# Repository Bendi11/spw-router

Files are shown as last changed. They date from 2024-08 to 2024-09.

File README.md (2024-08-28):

# 8 Port SpaceWire Router
A hobby-grade [SpaceWire](https://www.esa.int/Enabling_Support/Space_Engineering_Technology/Onboard_Computers_and_Data_Handling/SpaceWire) router
aiming for full **ECSS-E-ST-50-12C** compliance utilizing a Xilinx Artix 7 FPGA.

## Hardware Development
KiCad schematics and board design files for the board are stored in the `hw/board` directory.
Custom footprints and 3D models are placed into the `hw/models` directory.

## FPGA
Verilog sources are located in the `rtl/src` directory, and both the synthesis and simulation
processes are managed by CMake.

Currently, the FPGA bitstream is generated with a fully open-source
[yosys](https://github.com/YosysHQ/yosys) + [nextpnr-xilinx](https://github.com/gatecat/nextpnr-xilinx) flow,
and does not require the Xilinx Vivado software.
Paths to the required tools must currently be provided in an `env.cmake` file located in the
`rtl/cmake` directory, which must set the following:

| Variable Name | Description |
| :---: | --- |
| **YOSYS** | Path to the `yosys` binary |
| **NEXTPNR_XILINX** | Path to the `nextpnr-xilinx` binary, usually found at the root of the `nextpnr-xilinx` repository after building |
| **XRAY_DB_DIR** | Path to the Project X-Ray database |
| **XRAY_FASM2FRAMES** | Command to use the `fasm2frames` tool provided in Project X-Ray. This python script may have to run in Project X-Ray's virtual environment, so this variable is typically `"${PRJXRAY_DIR}/env/bin/python3" "${XRAY_DIR}/utils/fasm2frames.py"` |
| **XRAY_XC7FRAMES2BIT** | Path to the Project X-Ray's `xc7frames2bit` binary, usually in `${PRJXRAY_DIR}/build/tools/` |

### Example env.cmake
```cmake
set(NEXTPNR_XILINX_DIR "$ENV{HOME}/nextpnr-xilinx")
set(XRAY_DIR "$ENV{HOME}/prjxray")
set(XRAY_DB_DIR "${NEXTPNR_XILINX_DIR}/xilinx/external/prjxray-db")

set(YOSYS "yosys")
set(NEXTPNR_XILINX "${NEXTPNR_XILINX_DIR}/nextpnr-xilinx")
set(XRAY_FASM2FRAMES "${XRAY_DIR}/env/bin/python3" "${XRAY_DIR}/utils/fasm2frames.py")
set(XC7FRAMES2BIT "${XRAY_DIR}/build/tools/xc7frames2bit")
```

Design verification is performed with [Verilator](https://www.veripool.org/verilator/), with simulation
shims for Xilinx hard IP located in the `rtl/sim/verilog` directory.

## STM32 Software
`TODO`

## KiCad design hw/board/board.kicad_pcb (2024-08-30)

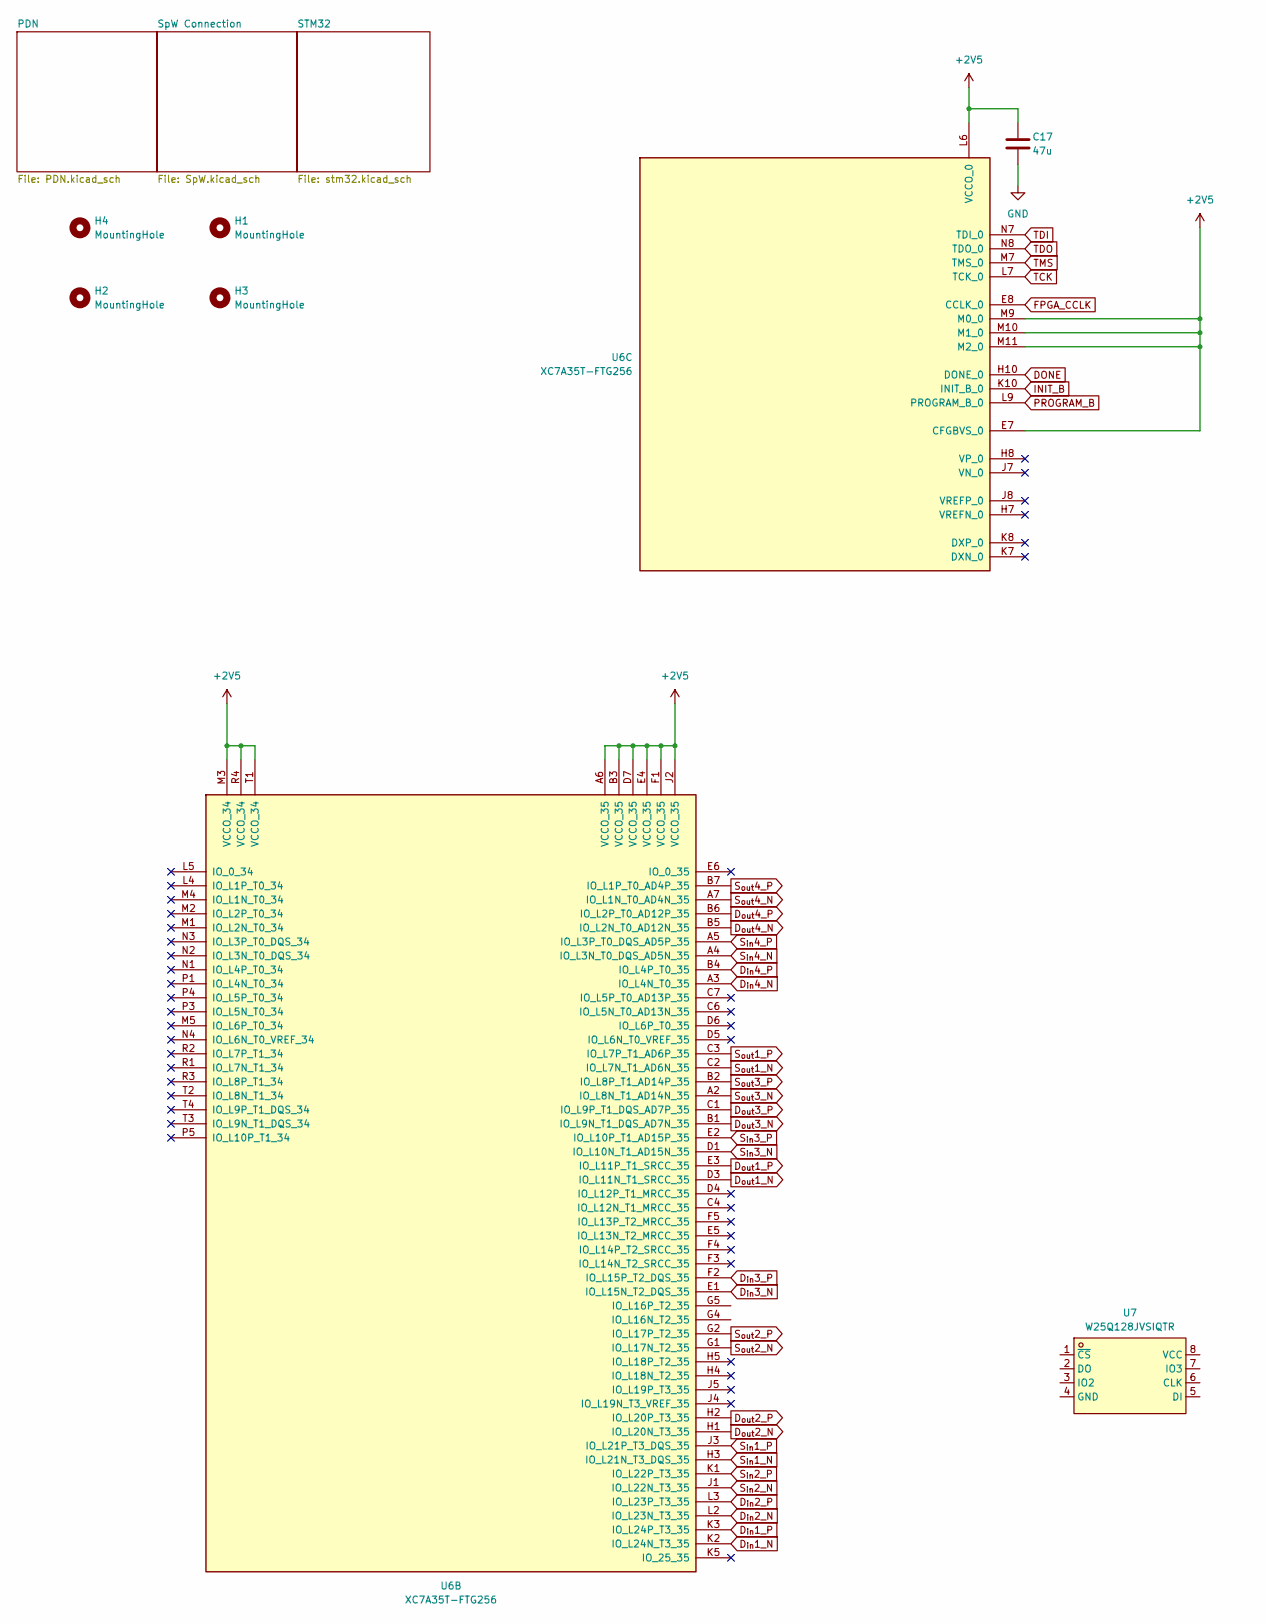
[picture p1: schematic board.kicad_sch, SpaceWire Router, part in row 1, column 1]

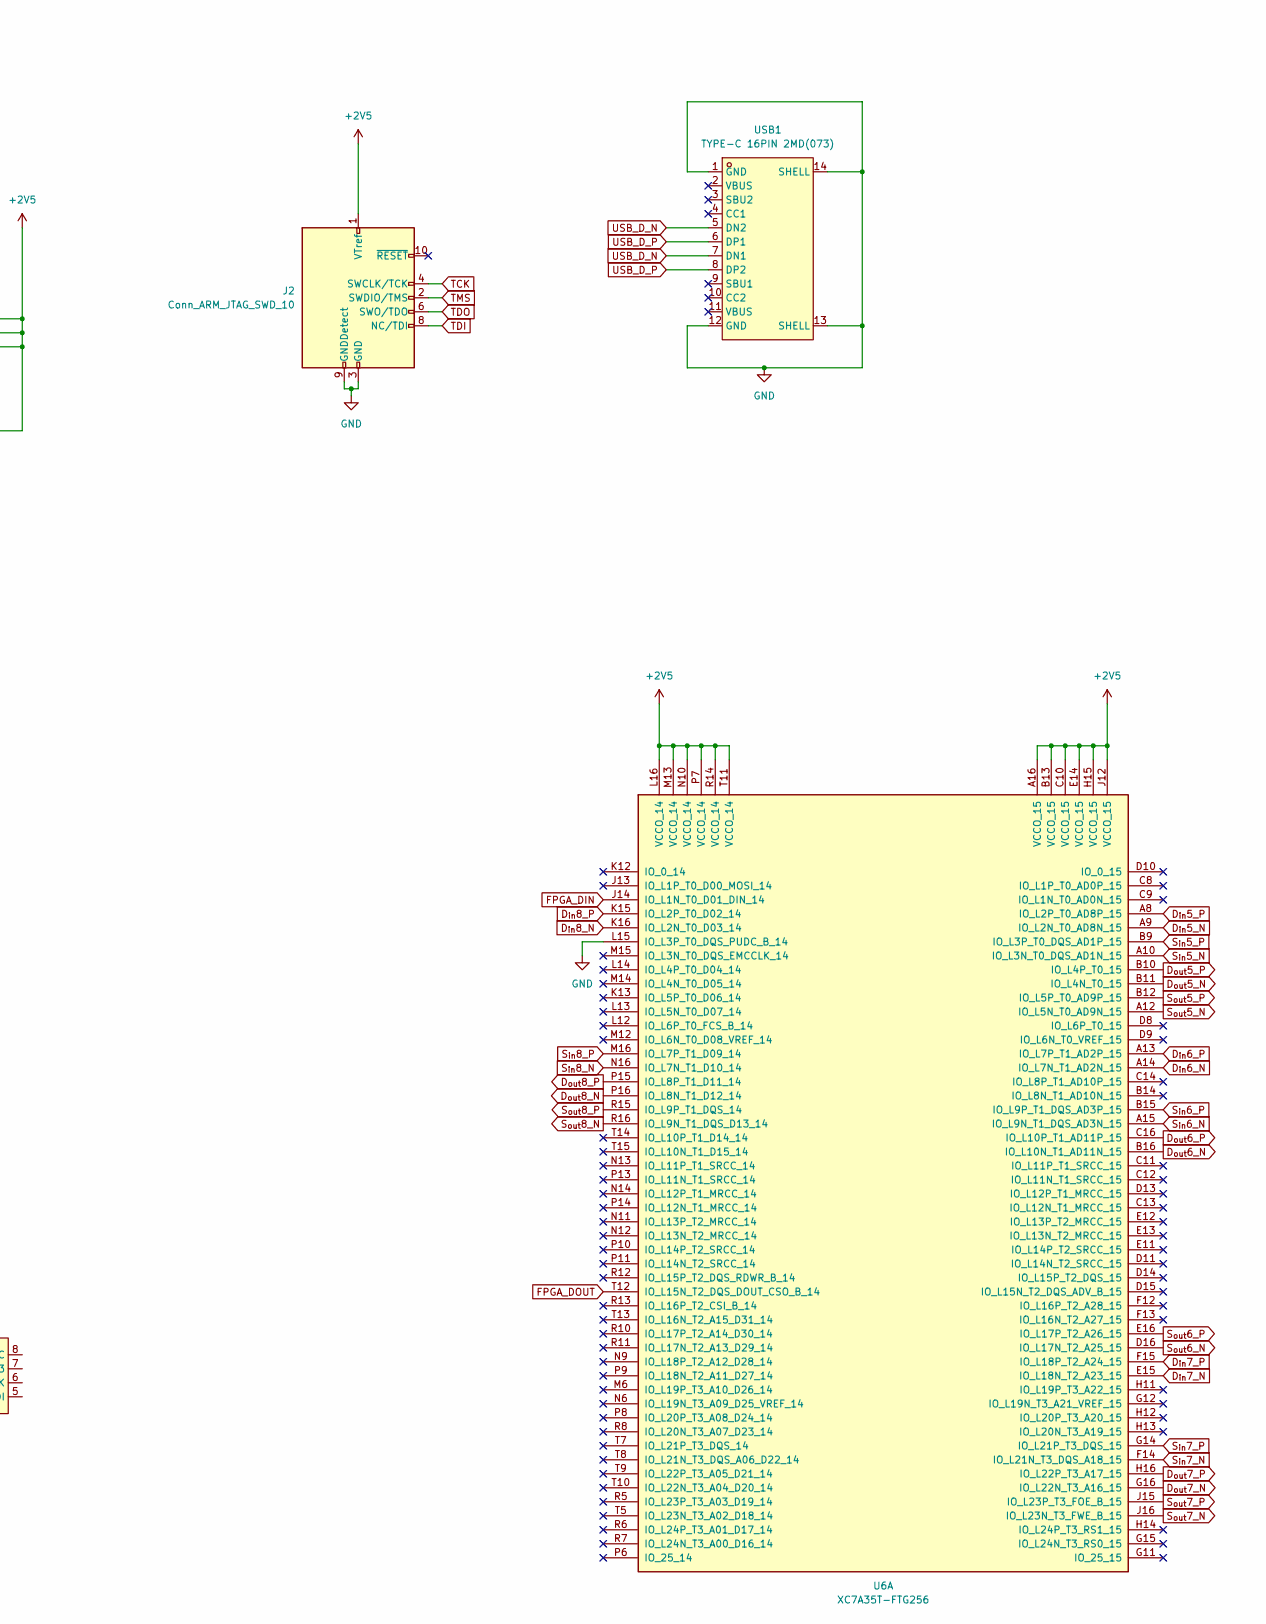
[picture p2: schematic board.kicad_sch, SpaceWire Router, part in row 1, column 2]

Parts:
C17: 47u; C_0805_2012Metric
H1, H2, H3, H4: MountingHole; MountingHole_2.2mm_M2
J2: Conn_ARM_JTAG_SWD_10; PinHeader_2x05_P1.27mm_Vertical
U6: XC7A35T-FTG256; Xilinx_FTG256
U7: W25Q128JVSIQTR; SOIC-8_L5.3-W5.3-P1.27-LS8.0-BL; LCSC Part C97521
USB1: TYPE-C 16PIN 2MD(073); USB-C-SMD_TYPE-C-6PIN-2MD-073; LCSC Part C2765186

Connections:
+2V5: C17.1, J2.1 (VTref), U6.A6 (VCCO_35), U6.A16 (VCCO_15), U6.B3 (VCCO_35), U6.B13 (VCCO_15), U6.C10 (VCCO_15), U6.D7 (VCCO_35), U6.E4 (VCCO_35), U6.E7 (CFGBVS_0), U6.E14 (VCCO_15), U6.F1 (VCCO_35), U6.H15 (VCCO_15), U6.J2 (VCCO_35), U6.J12 (VCCO_15), U6.L6 (VCCO_0), U6.L16 (VCCO_14), U6.M3 (VCCO_34), U6.M9 (M0_0), U6.M10 (M1_0), U6.M11 (M2_0), U6.M13 (VCCO_14), U6.N10 (VCCO_14), U6.P7 (VCCO_14), U6.R4 (VCCO_34), U6.R14 (VCCO_14), U6.T1 (VCCO_34), U6.T11 (VCCO_14); also elsewhere on the board
DONE: U6.H10 (DONE_0); also elsewhere on the board
D_{in}1_N: U6.K2 (IO_L24N_T3_35); also elsewhere on the board
D_{in}1_P: U6.K3 (IO_L24P_T3_35); also elsewhere on the board
D_{in}2_N: U6.L2 (IO_L23N_T3_35); also elsewhere on the board
D_{in}2_P: U6.L3 (IO_L23P_T3_35); also elsewhere on the board
D_{in}3_N: U6.E1 (IO_L15N_T2_DQS_35); also elsewhere on the board
D_{in}3_P: U6.F2 (IO_L15P_T2_DQS_35); also elsewhere on the board
D_{in}4_N: U6.A3 (IO_L4N_T0_35); also elsewhere on the board
D_{in}4_P: U6.B4 (IO_L4P_T0_35); also elsewhere on the board
D_{in}5_N: U6.A9 (IO_L2N_T0_AD8N_15); also elsewhere on the board
D_{in}5_P: U6.A8 (IO_L2P_T0_AD8P_15); also elsewhere on the board
D_{in}6_N: U6.A14 (IO_L7N_T1_AD2N_15); also elsewhere on the board
D_{in}6_P: U6.A13 (IO_L7P_T1_AD2P_15); also elsewhere on the board
D_{in}7_N: U6.E15 (IO_L18N_T2_A23_15); also elsewhere on the board
D_{in}7_P: U6.F15 (IO_L18P_T2_A24_15); also elsewhere on the board
D_{in}8_N: U6.K16 (IO_L2N_T0_D03_14); also elsewhere on the board
D_{in}8_P: U6.K15 (IO_L2P_T0_D02_14); also elsewhere on the board
D_{out}1_N: U6.D3 (IO_L11N_T1_SRCC_35); also elsewhere on the board
D_{out}1_P: U6.E3 (IO_L11P_T1_SRCC_35); also elsewhere on the board
D_{out}2_N: U6.H1 (IO_L20N_T3_35); also elsewhere on the board
D_{out}2_P: U6.H2 (IO_L20P_T3_35); also elsewhere on the board
D_{out}3_N: U6.B1 (IO_L9N_T1_DQS_AD7N_35); also elsewhere on the board
D_{out}3_P: U6.C1 (IO_L9P_T1_DQS_AD7P_35); also elsewhere on the board
D_{out}4_N: U6.B5 (IO_L2N_T0_AD12N_35); also elsewhere on the board
D_{out}4_P: U6.B6 (IO_L2P_T0_AD12P_35); also elsewhere on the board
D_{out}5_N: U6.B11 (IO_L4N_T0_15); also elsewhere on the board
D_{out}5_P: U6.B10 (IO_L4P_T0_15); also elsewhere on the board
D_{out}6_N: U6.B16 (IO_L10N_T1_AD11N_15); also elsewhere on the board
D_{out}6_P: U6.C16 (IO_L10P_T1_AD11P_15); also elsewhere on the board
D_{out}7_N: U6.G16 (IO_L22N_T3_A16_15); also elsewhere on the board
D_{out}7_P: U6.H16 (IO_L22P_T3_A17_15); also elsewhere on the board
D_{out}8_N: U6.P16 (IO_L8N_T1_D12_14); also elsewhere on the board
D_{out}8_P: U6.P15 (IO_L8P_T1_D11_14); also elsewhere on the board
FPGA_CCLK: U6.E8 (CCLK_0); also elsewhere on the board
FPGA_DIN: U6.J14 (IO_L1N_T0_D01_DIN_14); also elsewhere on the board
FPGA_DOUT: U6.T12 (IO_L15N_T2_DQS_DOUT_CSO_B_14); also elsewhere on the board
GND: C17.2, J2.3 (GND), J2.5 (GND), J2.9 (GNDDetect), U6.L15 (IO_L3P_T0_DQS_PUDC_B_14), USB1.1 (GND), USB1.12 (GND), USB1.13 (SHELL), USB1.14 (SHELL); also elsewhere on the board
INIT_B: U6.K10 (INIT_B_0); also elsewhere on the board
PROGRAM_B: U6.L9 (PROGRAM_B_0); also elsewhere on the board
S_{in}1_N: U6.H3 (IO_L21N_T3_DQS_35); also elsewhere on the board
S_{in}1_P: U6.J3 (IO_L21P_T3_DQS_35); also elsewhere on the board
S_{in}2_N: U6.J1 (IO_L22N_T3_35); also elsewhere on the board
S_{in}2_P: U6.K1 (IO_L22P_T3_35); also elsewhere on the board
S_{in}3_N: U6.D1 (IO_L10N_T1_AD15N_35); also elsewhere on the board
S_{in}3_P: U6.E2 (IO_L10P_T1_AD15P_35); also elsewhere on the board
S_{in}4_N: U6.A4 (IO_L3N_T0_DQS_AD5N_35); also elsewhere on the board
S_{in}4_P: U6.A5 (IO_L3P_T0_DQS_AD5P_35); also elsewhere on the board
S_{in}5_N: U6.A10 (IO_L3N_T0_DQS_AD1N_15); also elsewhere on the board
S_{in}5_P: U6.B9 (IO_L3P_T0_DQS_AD1P_15); also elsewhere on the board
S_{in}6_N: U6.A15 (IO_L9N_T1_DQS_AD3N_15); also elsewhere on the board
S_{in}6_P: U6.B15 (IO_L9P_T1_DQS_AD3P_15); also elsewhere on the board
S_{in}7_N: U6.F14 (IO_L21N_T3_DQS_A18_15); also elsewhere on the board
S_{in}7_P: U6.G14 (IO_L21P_T3_DQS_15); also elsewhere on the board
S_{in}8_N: U6.N16 (IO_L7N_T1_D10_14); also elsewhere on the board
S_{in}8_P: U6.M16 (IO_L7P_T1_D09_14); also elsewhere on the board
S_{out}1_N: U6.C2 (IO_L7N_T1_AD6N_35); also elsewhere on the board
S_{out}1_P: U6.C3 (IO_L7P_T1_AD6P_35); also elsewhere on the board
S_{out}2_N: U6.G1 (IO_L17N_T2_35); also elsewhere on the board
S_{out}2_P: U6.G2 (IO_L17P_T2_35); also elsewhere on the board
S_{out}3_N: U6.A2 (IO_L8N_T1_AD14N_35); also elsewhere on the board
S_{out}3_P: U6.B2 (IO_L8P_T1_AD14P_35); also elsewhere on the board
S_{out}4_N: U6.A7 (IO_L1N_T0_AD4N_35); also elsewhere on the board
S_{out}4_P: U6.B7 (IO_L1P_T0_AD4P_35); also elsewhere on the board
S_{out}5_N: U6.A12 (IO_L5N_T0_AD9N_15); also elsewhere on the board
S_{out}5_P: U6.B12 (IO_L5P_T0_AD9P_15); also elsewhere on the board
S_{out}6_N: U6.D16 (IO_L17N_T2_A25_15); also elsewhere on the board
S_{out}6_P: U6.E16 (IO_L17P_T2_A26_15); also elsewhere on the board
S_{out}7_N: U6.J16 (IO_L23N_T3_FWE_B_15); also elsewhere on the board
S_{out}7_P: U6.J15 (IO_L23P_T3_FOE_B_15); also elsewhere on the board
S_{out}8_N: U6.R16 (IO_L9N_T1_DQS_D13_14); also elsewhere on the board
S_{out}8_P: U6.R15 (IO_L9P_T1_DQS_14); also elsewhere on the board
TCK: J2.4 (SWCLK/TCK), U6.L7 (TCK_0)
TDI: J2.8 (NC/TDI), U6.N7 (TDI_0)
TDO: J2.6 (SWO/TDO), U6.N8 (TDO_0)
TMS: J2.2 (SWDIO/TMS), U6.M7 (TMS_0)
USB_D_N: USB1.5 (DN2), USB1.7 (DN1); also elsewhere on the board
USB_D_P: USB1.6 (DP1), USB1.8 (DP2); also elsewhere on the board

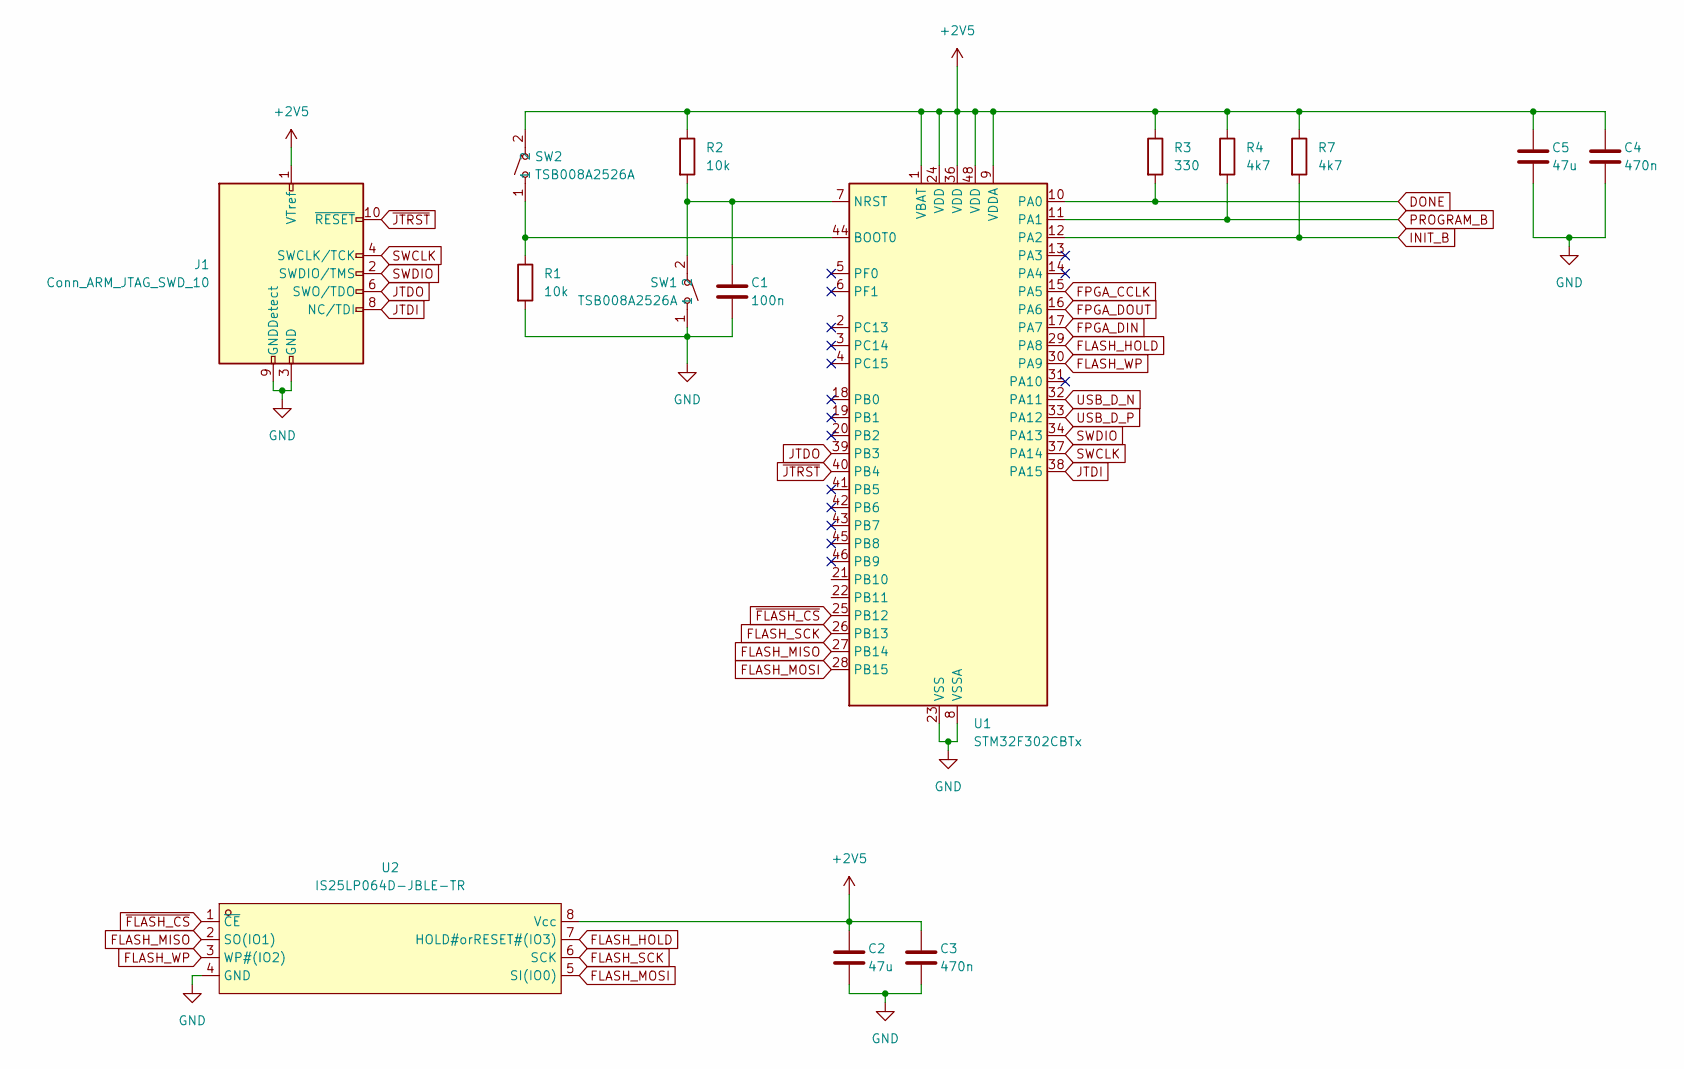
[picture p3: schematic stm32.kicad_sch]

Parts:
C1: 100n; C_0805_2012Metric
C2, C5: 47u; C_0805_2012Metric
C3, C4: 470n; C_0805_2012Metric
J1: Conn_ARM_JTAG_SWD_10; PinHeader_2x05_P1.27mm_Vertical
R1, R2: 10k; R_0805_2012Metric
R3: 330; R_0805_2012Metric
R4, R7: 4k7; R_0805_2012Metric
SW1, SW2: TSB008A2526A; SW-SMD_L6.0-W3.5-LS8.0; LCSC Part C2888456
U1: STM32F302CBTx; LQFP-48_7x7mm_P0.5mm
U2: IS25LP064D-JBLE-TR; SOIC-8_L5.3-W5.3-P1.27-LS7.9-BL; LCSC Part C5183018

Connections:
+2V5: C2.1, C3.1, C4.1, C5.1, J1.1 (VTref), R2.1, R3.1, R4.1, R7.1, SW2.2, U1.1 (VBAT), U1.9 (VDDA), U1.24 (VDD), U1.36 (VDD), U1.48 (VDD), U2.8 (Vcc); also elsewhere on the board
DONE: R3.2, U1.10 (PA0); also elsewhere on the board
FLASH_HOLD: U1.29 (PA8), U2.7 (HOLD#orRESET#(IO3))
FLASH_MISO: U1.27 (PB14), U2.2 (SO(IO1))
FLASH_MOSI: U1.28 (PB15), U2.5 (SI(IO0))
FLASH_SCK: U1.26 (PB13), U2.6 (SCK)
FLASH_WP: U1.30 (PA9), U2.3 (WP#(IO2))
FPGA_CCLK: U1.15 (PA5); also elsewhere on the board
FPGA_DIN: U1.17 (PA7); also elsewhere on the board
FPGA_DOUT: U1.16 (PA6); also elsewhere on the board
GND: C1.2, C2.2, C3.2, C4.2, C5.2, J1.3 (GND), J1.5 (GND), J1.9 (GNDDetect), R1.2, SW1.1, U1.8 (VSSA), U1.23 (VSS), U1.35 (VSS), U1.47 (VSS), U2.4 (GND); also elsewhere on the board
INIT_B: R7.2, U1.12 (PA2); also elsewhere on the board
JTDI: J1.8 (NC/TDI), U1.38 (PA15)
JTDO: J1.6 (SWO/TDO), U1.39 (PB3)
unnamed: R1.1, SW2.1, U1.44 (BOOT0)
unnamed: C1.1, R2.2, SW1.2, U1.7 (NRST)
PROGRAM_B: R4.2, U1.11 (PA1); also elsewhere on the board
SWCLK: J1.4 (SWCLK/TCK), U1.37 (PA14)
SWDIO: J1.2 (SWDIO/TMS), U1.34 (PA13)
USB_D_N: U1.32 (PA11); also elsewhere on the board
USB_D_P: U1.33 (PA12); also elsewhere on the board
~FLASH_CS: U1.25 (PB12), U2.1 (~CE)
~JTRST: J1.10 (~RESET), U1.40 (PB4)

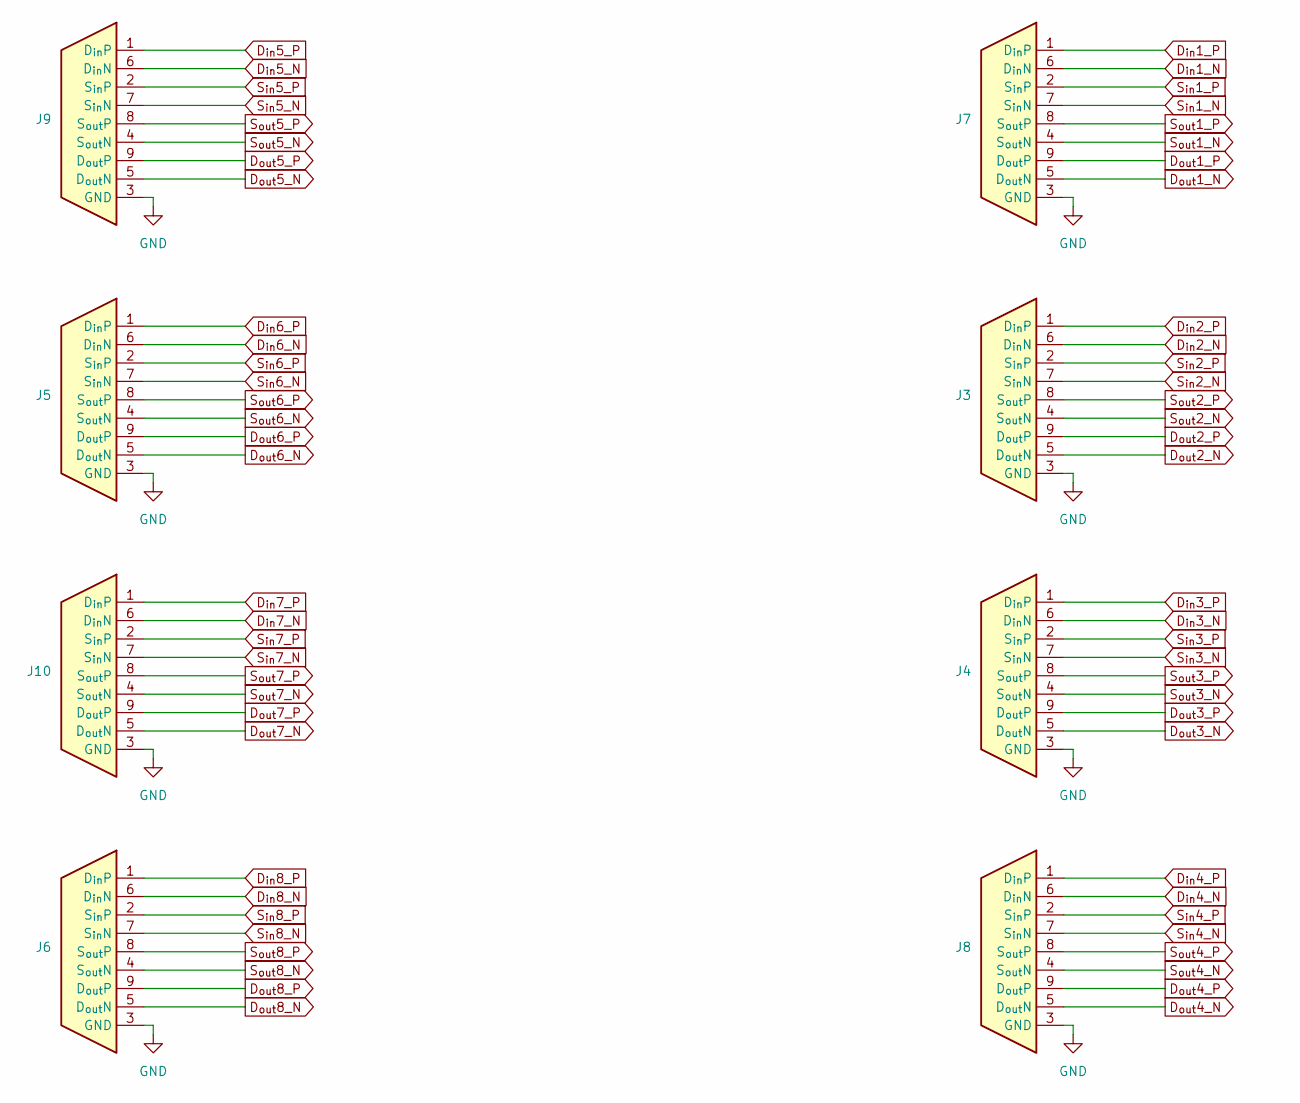
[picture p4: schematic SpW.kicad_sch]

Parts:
J3, J4, J5, J6, J7, J8, J9, J10: DE9_Pins

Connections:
D_{in}1_N: J7.6 (D_{in}N); also elsewhere on the board
D_{in}1_P: J7.1 (D_{in}P); also elsewhere on the board
D_{in}2_N: J3.6 (D_{in}N); also elsewhere on the board
D_{in}2_P: J3.1 (D_{in}P); also elsewhere on the board
D_{in}3_N: J4.6 (D_{in}N); also elsewhere on the board
D_{in}3_P: J4.1 (D_{in}P); also elsewhere on the board
D_{in}4_N: J8.6 (D_{in}N); also elsewhere on the board
D_{in}4_P: J8.1 (D_{in}P); also elsewhere on the board
D_{in}5_N: J9.6 (D_{in}N); also elsewhere on the board
D_{in}5_P: J9.1 (D_{in}P); also elsewhere on the board
D_{in}6_N: J5.6 (D_{in}N); also elsewhere on the board
D_{in}6_P: J5.1 (D_{in}P); also elsewhere on the board
D_{in}7_N: J10.6 (D_{in}N); also elsewhere on the board
D_{in}7_P: J10.1 (D_{in}P); also elsewhere on the board
D_{in}8_N: J6.6 (D_{in}N); also elsewhere on the board
D_{in}8_P: J6.1 (D_{in}P); also elsewhere on the board
D_{out}1_N: J7.5 (D_{out}N); also elsewhere on the board
D_{out}1_P: J7.9 (D_{out}P); also elsewhere on the board
D_{out}2_N: J3.5 (D_{out}N); also elsewhere on the board
D_{out}2_P: J3.9 (D_{out}P); also elsewhere on the board
D_{out}3_N: J4.5 (D_{out}N); also elsewhere on the board
D_{out}3_P: J4.9 (D_{out}P); also elsewhere on the board
D_{out}4_N: J8.5 (D_{out}N); also elsewhere on the board
D_{out}4_P: J8.9 (D_{out}P); also elsewhere on the board
D_{out}5_N: J9.5 (D_{out}N); also elsewhere on the board
D_{out}5_P: J9.9 (D_{out}P); also elsewhere on the board
D_{out}6_N: J5.5 (D_{out}N); also elsewhere on the board
D_{out}6_P: J5.9 (D_{out}P); also elsewhere on the board
D_{out}7_N: J10.5 (D_{out}N); also elsewhere on the board
D_{out}7_P: J10.9 (D_{out}P); also elsewhere on the board
D_{out}8_N: J6.5 (D_{out}N); also elsewhere on the board
D_{out}8_P: J6.9 (D_{out}P); also elsewhere on the board
GND: J3.3 (GND), J4.3 (GND), J5.3 (GND), J6.3 (GND), J7.3 (GND), J8.3 (GND), J9.3 (GND), J10.3 (GND); also elsewhere on the board
S_{in}1_N: J7.7 (S_{in}N); also elsewhere on the board
S_{in}1_P: J7.2 (S_{in}P); also elsewhere on the board
S_{in}2_N: J3.7 (S_{in}N); also elsewhere on the board
S_{in}2_P: J3.2 (S_{in}P); also elsewhere on the board
S_{in}3_N: J4.7 (S_{in}N); also elsewhere on the board
S_{in}3_P: J4.2 (S_{in}P); also elsewhere on the board
S_{in}4_N: J8.7 (S_{in}N); also elsewhere on the board
S_{in}4_P: J8.2 (S_{in}P); also elsewhere on the board
S_{in}5_N: J9.7 (S_{in}N); also elsewhere on the board
S_{in}5_P: J9.2 (S_{in}P); also elsewhere on the board
S_{in}6_N: J5.7 (S_{in}N); also elsewhere on the board
S_{in}6_P: J5.2 (S_{in}P); also elsewhere on the board
S_{in}7_N: J10.7 (S_{in}N); also elsewhere on the board
S_{in}7_P: J10.2 (S_{in}P); also elsewhere on the board
S_{in}8_N: J6.7 (S_{in}N); also elsewhere on the board
S_{in}8_P: J6.2 (S_{in}P); also elsewhere on the board
S_{out}1_N: J7.4 (S_{out}N); also elsewhere on the board
S_{out}1_P: J7.8 (S_{out}P); also elsewhere on the board
S_{out}2_N: J3.4 (S_{out}N); also elsewhere on the board
S_{out}2_P: J3.8 (S_{out}P); also elsewhere on the board
S_{out}3_N: J4.4 (S_{out}N); also elsewhere on the board
S_{out}3_P: J4.8 (S_{out}P); also elsewhere on the board
S_{out}4_N: J8.4 (S_{out}N); also elsewhere on the board
S_{out}4_P: J8.8 (S_{out}P); also elsewhere on the board
S_{out}5_N: J9.4 (S_{out}N); also elsewhere on the board
S_{out}5_P: J9.8 (S_{out}P); also elsewhere on the board
S_{out}6_N: J5.4 (S_{out}N); also elsewhere on the board
S_{out}6_P: J5.8 (S_{out}P); also elsewhere on the board
S_{out}7_N: J10.4 (S_{out}N); also elsewhere on the board
S_{out}7_P: J10.8 (S_{out}P); also elsewhere on the board
S_{out}8_N: J6.4 (S_{out}N); also elsewhere on the board
S_{out}8_P: J6.8 (S_{out}P); also elsewhere on the board

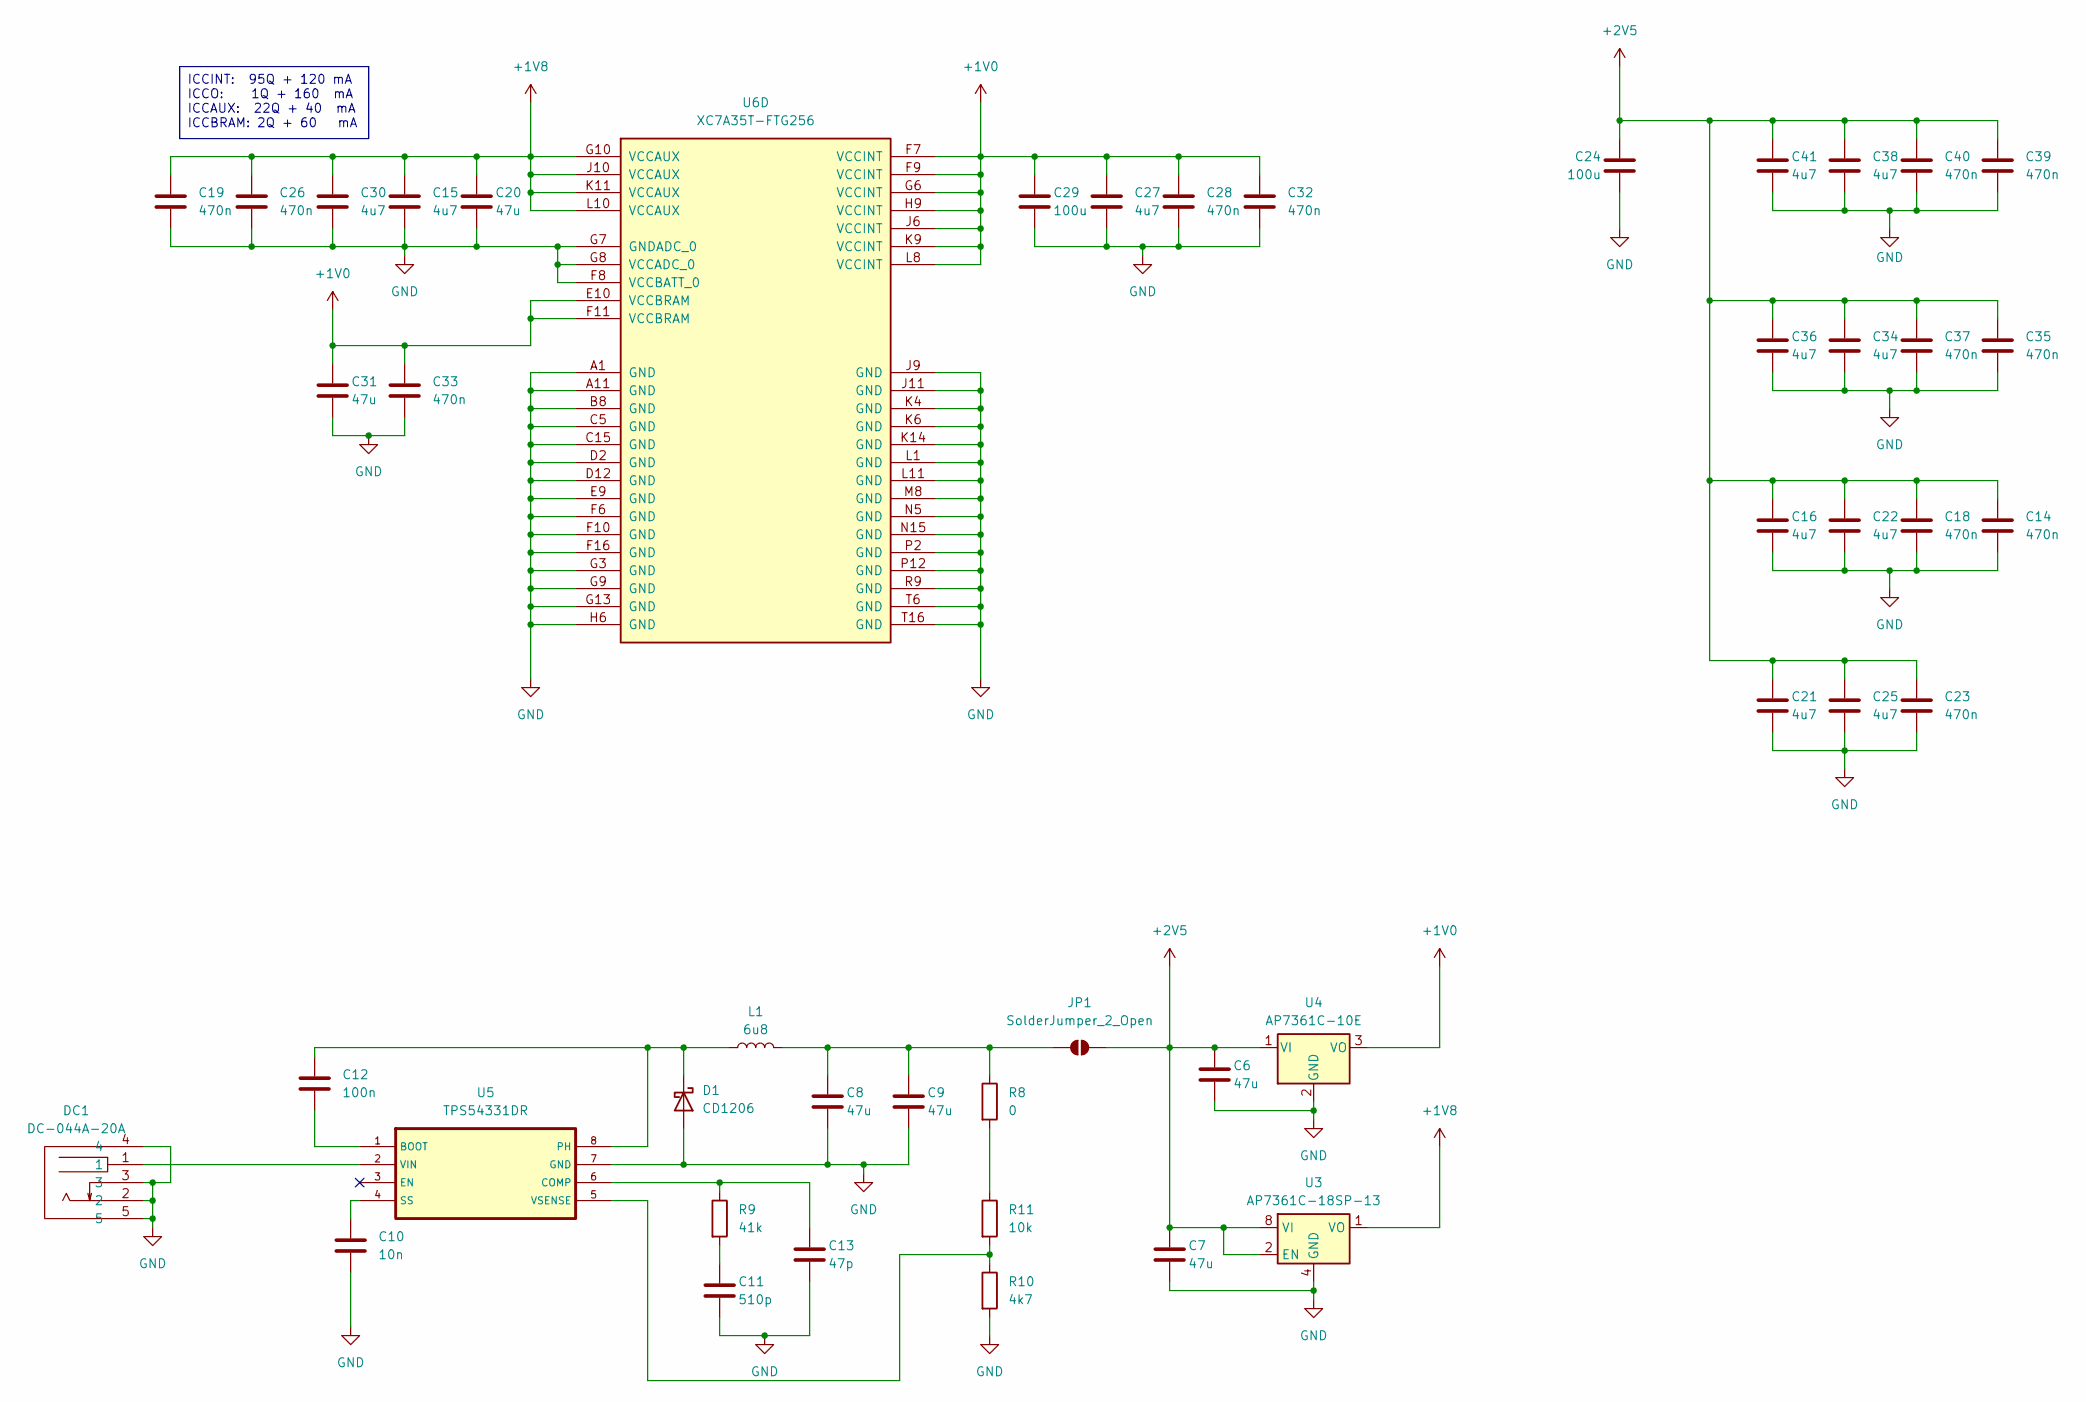
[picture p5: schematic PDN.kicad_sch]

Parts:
C6, C7, C8, C9, C20, C31: 47u; C_0805_2012Metric
C10: 10n; C_0805_2012Metric
C11: 510p; C_0805_2012Metric
C12: 100n; C_0805_2012Metric
C13: 47p; C_0805_2012Metric
C14, C18, C19, C23, C26, C28, C32, C33, C35, C37, C39, C40: 470n; C_0805_2012Metric
C15, C16, C21, C22, C25, C27, C30, C34, C36, C38, C41: 4u7; C_0805_2012Metric
C24, C29: 100u; C_0805_2012Metric
D1: CD1206; D_1206_3216Metric
DC1: DC-044A-20A; DC-IN-TH_DC-044A-20A; LCSC Part C129006
JP1: SolderJumper_2_Open; SolderJumper-2_P1.3mm_Open_TrianglePad1.0x1.5mm
L1: 6u8; IND-SMD_L11.6-W10.1
R8: 0; R_0805_2012Metric
R9: 41k; R_0805_2012Metric
R10: 4k7; R_0805_2012Metric
R11: 10k; R_0805_2012Metric
U3: AP7361C-18SP-13; SOIC-8-1EP_3.9x4.9mm_P1.27mm_EP2.41x3.3mm_ThermalVias
U4: AP7361C-10E; SOT-223-3_TabPin2
U5: TPS54331DR; SOIC127P599X175-8N
U6: XC7A35T-FTG256; Xilinx_FTG256

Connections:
+1V0: C27.1, C28.1, C29.1, C31.1, C32.1, C33.1, U4.3 (VO), U6.E10 (VCCBRAM), U6.F7 (VCCINT), U6.F9 (VCCINT), U6.F11 (VCCBRAM), U6.G6 (VCCINT), U6.H9 (VCCINT), U6.J6 (VCCINT), U6.K9 (VCCINT), U6.L8 (VCCINT)
+1V8: C15.1, C19.1, C20.1, C26.1, C30.1, U3.1 (VO), U6.G10 (VCCAUX), U6.J10 (VCCAUX), U6.K11 (VCCAUX), U6.L10 (VCCAUX)
+2V5: C6.1, C7.1, C14.1, C16.1, C18.1, C21.1, C22.1, C23.1, C24.1, C25.1, C34.1, C35.1, C36.1, C37.1, C38.1, C39.1, C40.1, C41.1, JP1.2 (B), U3.2 (EN), U3.8 (VI), U4.1 (VI); also elsewhere on the board
GND: C6.2, C7.2, C8.2, C9.2, C10.2, C11.2, C13.2, C14.2, C15.2, C16.2, C18.2, C19.2, C20.2, C21.2, C22.2, C23.2, C24.2, C25.2, C26.2, C27.2, C28.2, C29.2, C30.2, C31.2, C32.2, C33.2, C34.2, C35.2, C36.2, C37.2, C38.2, C39.2, C40.2, C41.2, D1.2 (A), DC1.2, DC1.3, DC1.4, DC1.5, R10.2, U3.4 (GND), U4.2 (GND), U5.7 (GND), U6.A1 (GND), U6.A11 (GND), U6.B8 (GND), U6.C5 (GND), U6.C15 (GND), U6.D2 (GND), U6.D12 (GND), U6.E9 (GND), U6.F6 (GND), U6.F8 (VCCBATT_0), U6.F10 (GND), U6.F16 (GND), U6.G3 (GND), U6.G7 (GNDADC_0), U6.G8 (VCCADC_0), U6.G9 (GND), U6.G13 (GND), U6.H6 (GND), U6.J9 (GND), U6.J11 (GND), U6.K4 (GND), U6.K6 (GND), U6.K14 (GND), U6.L1 (GND), U6.L11 (GND), U6.M8 (GND), U6.N5 (GND), U6.N15 (GND), U6.P2 (GND), U6.P12 (GND), U6.R9 (GND), U6.T6 (GND), U6.T16 (GND); also elsewhere on the board
unnamed: C11.1, R9.2
unnamed: C12.1, D1.1 (K), L1.1, U5.8 (PH)
unnamed: C8.1, C9.1, JP1.1 (A), L1.2, R8.1
unnamed: R8.2, R11.1
unnamed: C12.2, U5.1 (BOOT)
unnamed: C13.1, R9.1, U5.6 (COMP)
unnamed: C10.1, U5.4 (SS)
unnamed: DC1.1, U5.2 (VIN)
unnamed: R10.1, R11.2, U5.5 (VSENSE)

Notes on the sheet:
ICCINT: 95Q + 120 mA ICCO: 1Q + 160 mA ICCAUX: 22Q + 40 mA ICCBRAM: 2Q + 60 mA

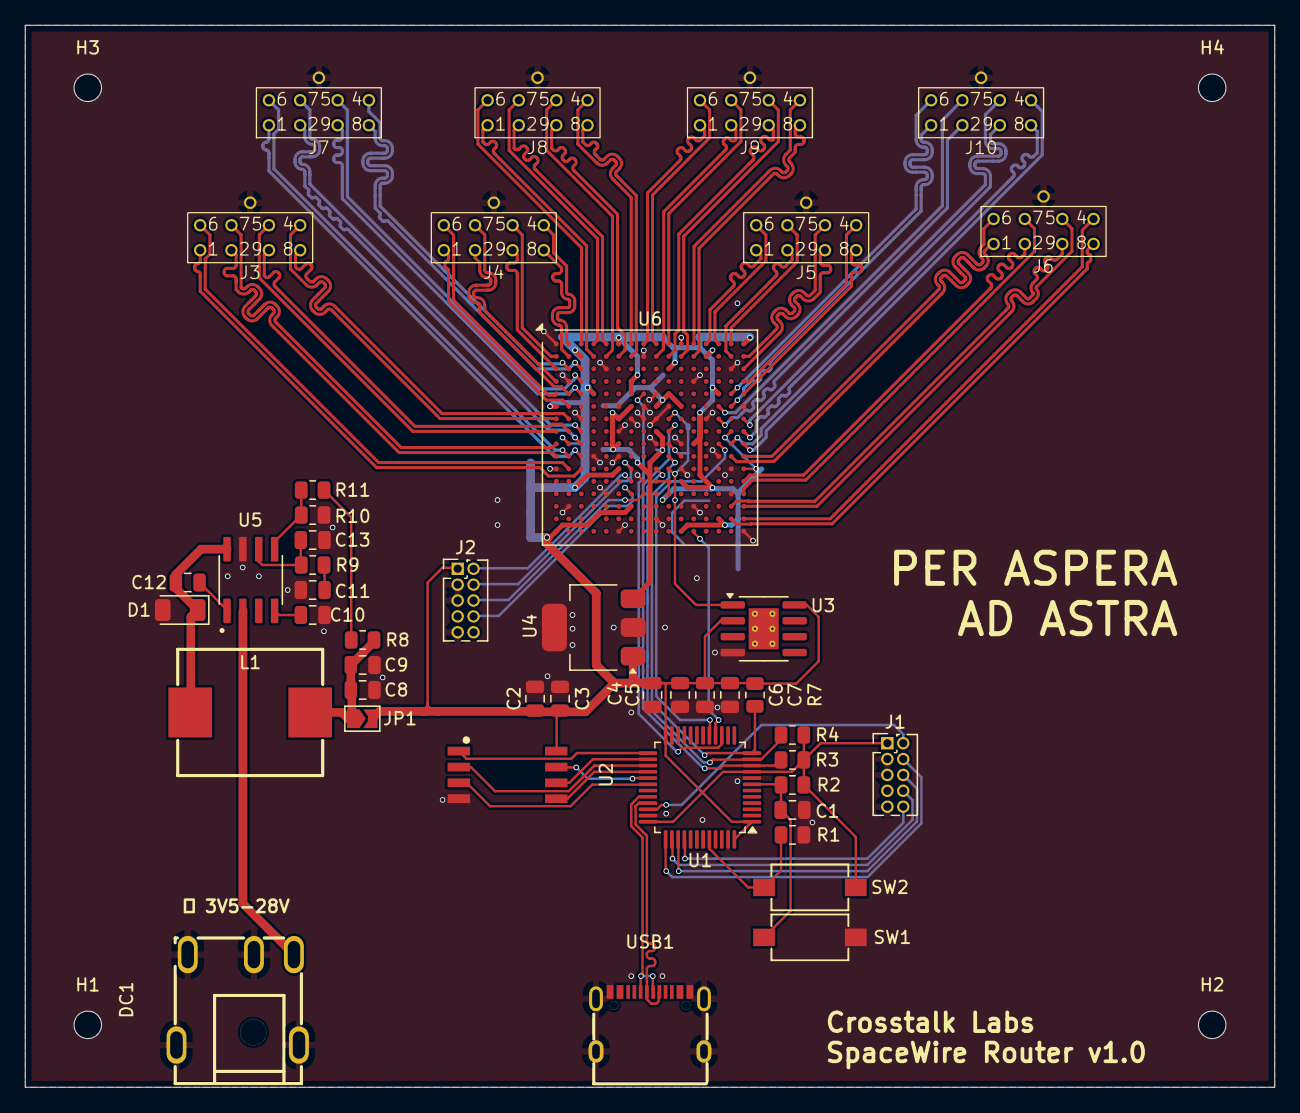
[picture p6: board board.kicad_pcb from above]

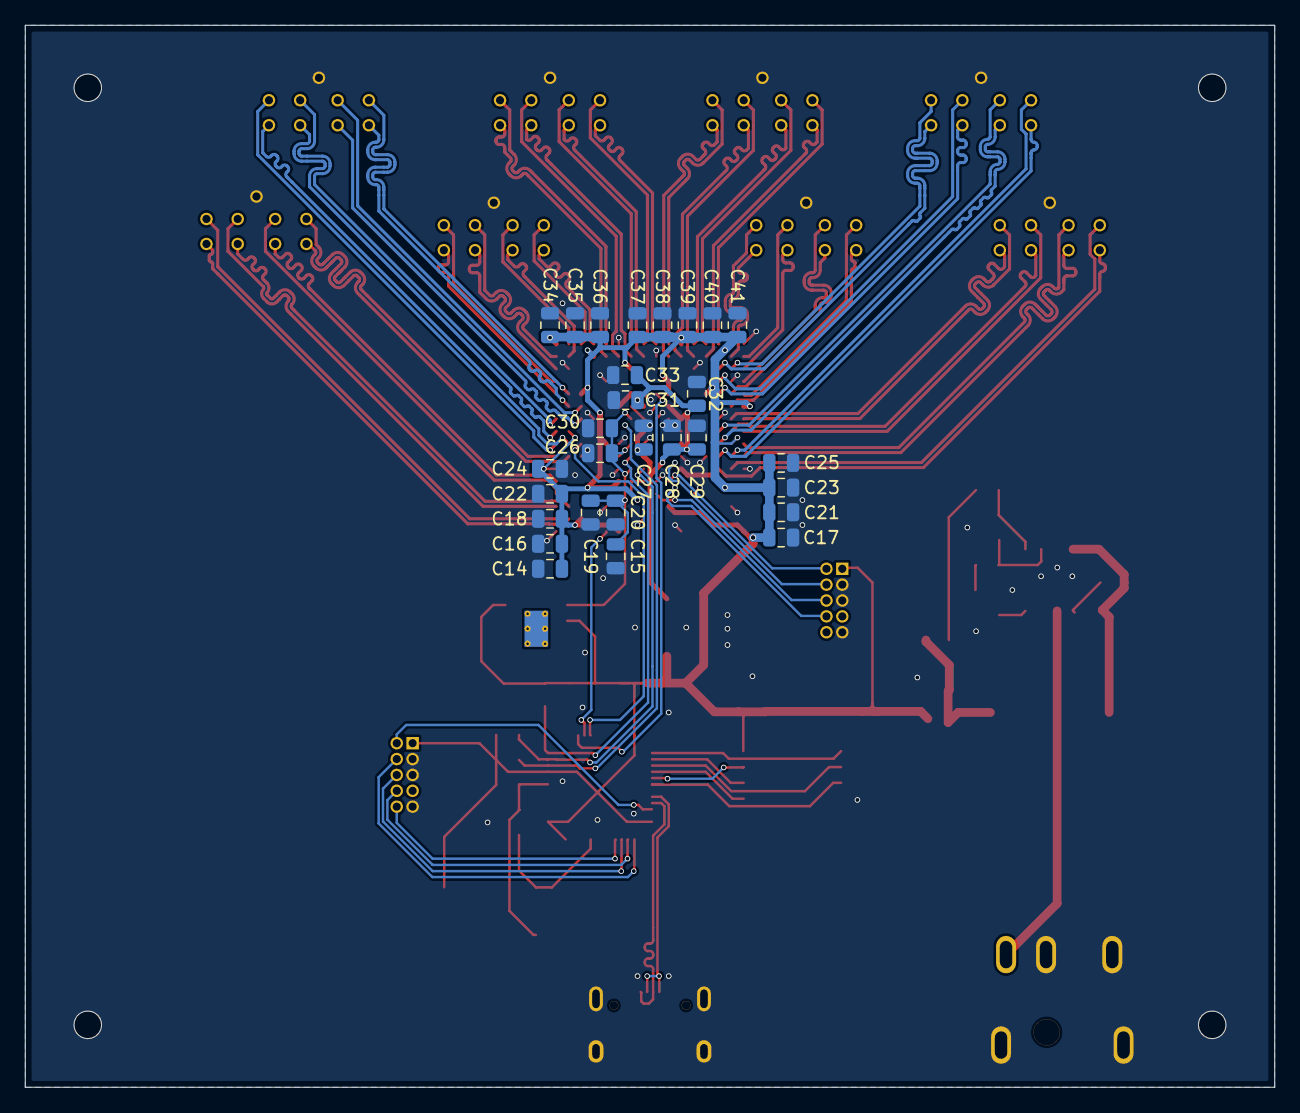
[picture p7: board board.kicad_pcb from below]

Board: 4 copper layers, 100.0 x 85.0 mm, 77 parts (28 on the bottom side), 102 nets.

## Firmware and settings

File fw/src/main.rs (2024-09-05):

#![no_std]
#![no_main]

mod flash;

use core::{ops::Deref, panic::PanicInfo};

use cortex_m_rt::entry;
use stm32f3::stm32f302::Peripherals;

#[panic_handler]
fn panic(pinfo: &PanicInfo) -> ! {
    loop {}
}

#[entry]
fn main() -> ! {
    let periph = Peripherals::take().unwrap();

    loop {
        cortex_m::asm::delay(1);
    }
}

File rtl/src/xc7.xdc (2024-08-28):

set_property LOC C11 [get_ports clk]
set_property IOSTANDARD LVCMOS25 [get_ports clk]

set_property LOC K3 [get_ports din_p[0]]
set_property IOSTANDARD LVDS_25 [get_ports din_p[0]]
set_property LOC K2 [get_ports din_n[0]]
set_property IOSTANDARD LVDS_25 [get_ports din_n[0]]

set_property LOC J3 [get_ports sin_p[0]]
set_property IOSTANDARD LVDS_25 [get_ports sin_p[0]]
set_property LOC H3 [get_ports sin_n[0]]
set_property IOSTANDARD LVDS_25 [get_ports sin_n[0]]

set_property LOC E3 [get_ports dout_p[0]]
set_property IOSTANDARD LVDS_25 [get_ports dout_p[0]]
set_property LOC D3 [get_ports dout_n[0]]
set_property IOSTANDARD LVDS_25 [get_ports dout_n[0]]

set_property LOC C3 [get_ports sout_p[0]]
set_property IOSTANDARD LVDS_25 [get_ports sout_p[0]]
set_property LOC C2 [get_ports sout_n[0]]
set_property IOSTANDARD LVDS_25 [get_ports sout_n[0]]



set_property LOC L3 [get_ports din_p[1]]
set_property IOSTANDARD LVDS_25 [get_ports din_p[1]]
set_property LOC L2 [get_ports din_n[1]]
set_property IOSTANDARD LVDS_25 [get_ports din_n[1]]

set_property LOC K1 [get_ports sin_p[1]]
set_property IOSTANDARD LVDS_25 [get_ports sin_p[1]]
set_property LOC J1 [get_ports sin_n[1]]
set_property IOSTANDARD LVDS_25 [get_ports sin_n[1]]

set_property LOC H2 [get_ports dout_p[1]]
set_property IOSTANDARD LVDS_25 [get_ports dout_p[1]]
set_property LOC H1 [get_ports dout_n[1]]
set_property IOSTANDARD LVDS_25 [get_ports dout_n[1]]

set_property LOC G2 [get_ports sout_p[1]]
set_property IOSTANDARD LVDS_25 [get_ports sout_p[1]]
set_property LOC G1 [get_ports sout_n[1]]
set_property IOSTANDARD LVDS_25 [get_ports sout_n[1]]



set_property LOC F2 [get_ports din_p[2]]
set_property IOSTANDARD LVDS_25 [get_ports din_p[2]]
set_property LOC E1 [get_ports din_n[2]]
set_property IOSTANDARD LVDS_25 [get_ports din_n[2]]

set_property LOC E2 [get_ports sin_p[2]]
set_property IOSTANDARD LVDS_25 [get_ports sin_p[2]]
set_property LOC D1 [get_ports sin_n[2]]
set_property IOSTANDARD LVDS_25 [get_ports sin_n[2]]

set_property LOC C1 [get_ports dout_p[2]]
set_property IOSTANDARD LVDS_25 [get_ports dout_p[2]]
set_property LOC B1 [get_ports dout_n[2]]
set_property IOSTANDARD LVDS_25 [get_ports dout_n[2]]

set_property LOC B2 [get_ports sout_p[2]]
set_property IOSTANDARD LVDS_25 [get_ports sout_p[2]]
set_property LOC A2 [get_ports sout_n[2]]
set_property IOSTANDARD LVDS_25 [get_ports sout_n[2]]



set_property LOC B4 [get_ports din_p[3]]
set_property IOSTANDARD LVDS_25 [get_ports din_p[3]]
set_property LOC A3 [get_ports din_n[3]]
set_property IOSTANDARD LVDS_25 [get_ports din_n[3]]

set_property LOC A5 [get_ports sin_p[3]]
set_property IOSTANDARD LVDS_25 [get_ports sin_p[3]]
set_property LOC A4 [get_ports sin_n[3]]
set_property IOSTANDARD LVDS_25 [get_ports sin_n[3]]

set_property LOC B6 [get_ports dout_p[3]]
set_property IOSTANDARD LVDS_25 [get_ports dout_p[3]]
set_property LOC B5 [get_ports dout_n[3]]
set_property IOSTANDARD LVDS_25 [get_ports dout_n[3]]

set_property LOC B7 [get_ports sout_p[3]]
set_property IOSTANDARD LVDS_25 [get_ports sout_p[3]]
set_property LOC A7 [get_ports sout_n[3]]
set_property IOSTANDARD LVDS_25 [get_ports sout_n[3]]



set_property LOC A8 [get_ports din_p[4]]
set_property IOSTANDARD LVDS_25 [get_ports din_p[4]]
set_property LOC A9 [get_ports din_n[4]]
set_property IOSTANDARD LVDS_25 [get_ports din_n[4]]

set_property LOC B9 [get_ports sin_p[4]]
set_property IOSTANDARD LVDS_25 [get_ports sin_p[4]]
set_property LOC A10 [get_ports sin_n[4]]
set_property IOSTANDARD LVDS_25 [get_ports sin_n[4]]

set_property LOC B10 [get_ports dout_p[4]]
set_property IOSTANDARD LVDS_25 [get_ports dout_p[4]]
set_property LOC B11 [get_ports dout_n[4]]
set_property IOSTANDARD LVDS_25 [get_ports dout_n[4]]

set_property LOC B12 [get_ports sout_p[4]]
set_property IOSTANDARD LVDS_25 [get_ports sout_p[4]]
set_property LOC A12 [get_ports sout_n[4]]
set_property IOSTANDARD LVDS_25 [get_ports sout_n[4]]



set_property LOC A13 [get_ports din_p[5]]
set_property IOSTANDARD LVDS_25 [get_ports din_p[5]]
set_property LOC A14 [get_ports din_n[5]]
set_property IOSTANDARD LVDS_25 [get_ports din_n[5]]

set_property LOC B15 [get_ports sin_p[5]]
set_property IOSTANDARD LVDS_25 [get_ports sin_p[5]]
set_property LOC A15 [get_ports sin_n[5]]
set_property IOSTANDARD LVDS_25 [get_ports sin_n[5]]

set_property LOC C16 [get_ports dout_p[5]]
set_property IOSTANDARD LVDS_25 [get_ports dout_p[5]]
set_property LOC B16 [get_ports dout_n[5]]
set_property IOSTANDARD LVDS_25 [get_ports dout_n[5]]

set_property LOC E16 [get_ports sout_p[5]]
set_property IOSTANDARD LVDS_25 [get_ports sout_p[5]]
set_property LOC D16 [get_ports sout_n[5]]
set_property IOSTANDARD LVDS_25 [get_ports sout_n[5]]



set_property LOC F15 [get_ports din_p[6]]
set_property IOSTANDARD LVDS_25 [get_ports din_p[6]]
set_property LOC E15 [get_ports din_n[6]]
set_property IOSTANDARD LVDS_25 [get_ports din_n[6]]
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

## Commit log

2024-08-17 Added DE9 connector through hole footprints, initial filtering capacitors
    [board.kicad_pcb, board.kicad_sch]
2024-08-17 Added decoupling network following Xiling UG483
    [board.kicad_pcb, board.kicad_sch]
2024-08-19 Added DE9 connector footprint
    [PDN.kicad_sch, SPW-template.kicad_sch, SpW.kicad_sch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]
2024-08-20 Routed DE-9 connectors
    [PDN.kicad_sch, SpW.kicad_sch, SpW_translate.kicad_sch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]
2024-08-20 Began routing decoupling network
    [PDN.kicad_sch, board.kicad_pcb, board.kicad_sch]
2024-08-20 Added TPS54331 regulator schematic for 2v5 delivery
    [PDN.kicad_sch, board.kicad_pcb]
2024-08-21 Routed decoupling capacitors
    [PDN.kicad_sch, board.kicad_pcb, board.kicad_sch]
2024-08-21 Routed all voltage regulators
    [PDN.kicad_sch, board.kicad_pcb]
2024-08-23 Finished routing STM32 connection, resolved DRC errors
    [board.kicad_pcb, board.kicad_sch, stm32.kicad_sch]
2024-08-23 Began refactoring BGA fanout
    [PDN.kicad_sch, board.kicad_pcb, board.kicad_sch]
2024-08-26 Finished re-routing spacewire connectors
    [board.kicad_pcb, board.kicad_sch]
2024-08-26 Added reset + boot switches for STM32, re-routed power
    [PDN.kicad_sch, board.kicad_pcb, board.kicad_sch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]
2024-08-26 Added power connector, SWD/JTAG connectors
    [PDN.kicad_sch, board.kicad_pcb, board.kicad_sch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]
2024-08-26 Reannotated piece numbers
    [PDN.kicad_sch, SpW.kicad_sch, board.kicad_pcb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]
2024-08-26 Added capacitor for STM32 NRST
    [PDN.kicad_sch, board.kicad_pcb, board.kicad_sch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]
2024-08-26 Moved linear regulators away from FPGA
    [board.kicad_pcb]
2024-08-26 Cleaned up footprint placement, started BOM
    [board.kicad_pcb]
2024-08-26 Replaced inductor footprint
    [PDN.kicad_sch, board.kicad_pcb]
2024-08-27 Routed DOUT for FPGA
    [board.kicad_sch, stm32.kicad_sch]
2024-08-27 Updated silkscreen
    [board.kicad_pcb, board.kicad_sch]
2024-08-27 Fixed USB C port
    [board.kicad_pcb, board.kicad_sch]
2024-08-27 Removed unused 0 ohm resistor, add ground vias
    [board.kicad_pcb, board.kicad_sch]
2024-08-27 Additional ground stitching vias
    [PDN.kicad_sch, board.kicad_pcb]
2024-08-27 Mapped all DE9 connector pins for synthesis
2024-08-28 Switched to CMake for build system generation
2024-08-28 Fixed silkscreen overlaps, updated verilator shims
    [board.kicad_pcb]
2024-08-28 Updated net names for SPI bitstream upload
    [board.kicad_pcb, board.kicad_sch, stm32.kicad_sch]
2024-08-29 Reduced flash size
    [board.kicad_pcb, board.kicad_sch, stm32.kicad_sch]
2024-08-30 Updated verilog to more closely match ECSS standard for encoding layer
    [board.kicad_pcb, board.kicad_sch]
2024-09-05 Added SPI flash initialization
